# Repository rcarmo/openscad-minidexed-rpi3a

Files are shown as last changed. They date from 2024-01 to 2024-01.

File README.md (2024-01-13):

# MiniDexed RPI 3A Case

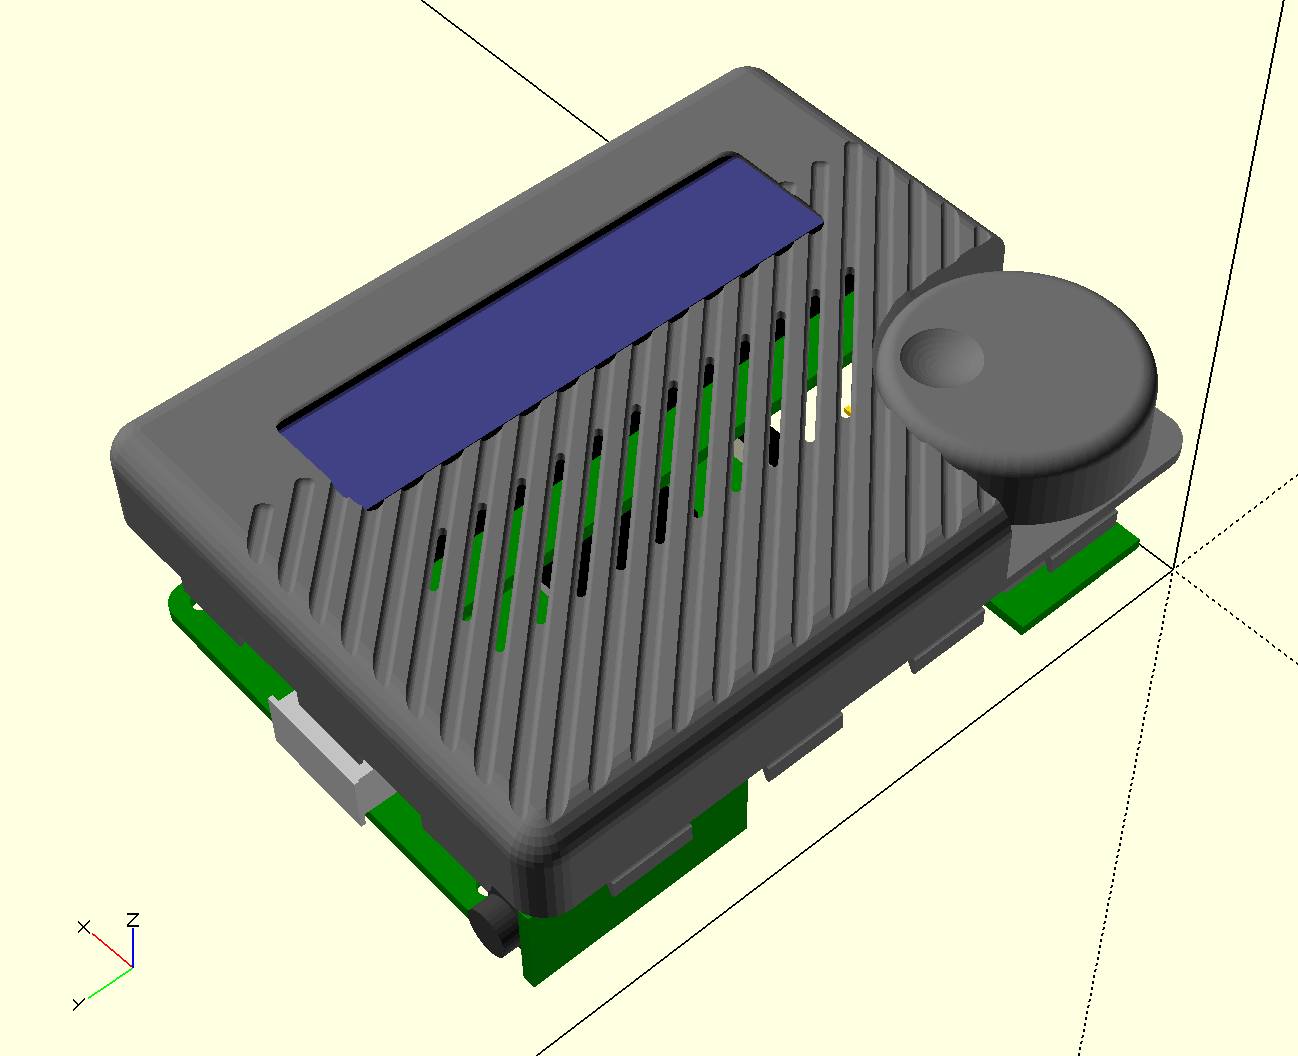
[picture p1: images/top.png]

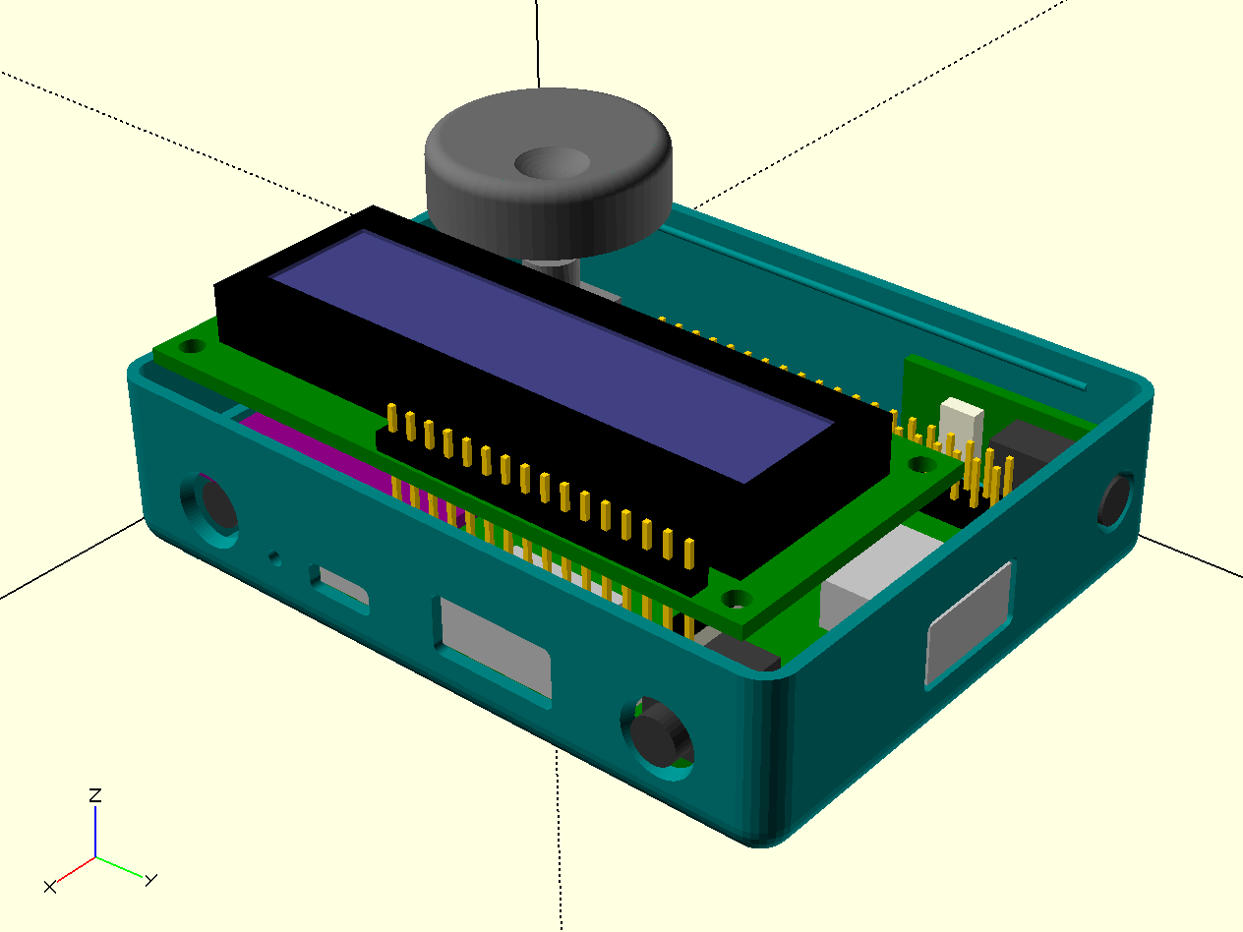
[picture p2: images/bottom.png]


This is a case for a [MiniDexed] synthesizer built with a Raspberry Pi 3A, a DAC and a custom board for a MIDI IN TRS jack (schematic included in the `kicad-mini-in` folder--I ended up just using a protoboard, so there's no real PCB data for that).

This repository includes the `STL` files for the case (top, bottom and knob), as well as the [OpenSCAD](https://openscad.org) files for the case and all boards (some of which I modified from some of the excellent libraries I keep tabs on [here](https://taoofmac.com/space/apps/openscad)).

There is also an (incomplete) slanted/oblique version of the case, which I may or may not finish.

## MIDI IN Schematic

This is a pretty simple schematic, and I ended up just using a protoboard for it. The TRS jack is a 2.5mm MIDI IN jack, and other than the [`H11L1M`](https://www.onsemi.com/products/interfaces/high-performance-optocouplers/high-speed-logic-gate-optocouplers/h11l1m) optocoupler, everything else is just a few resistors and capacitors:

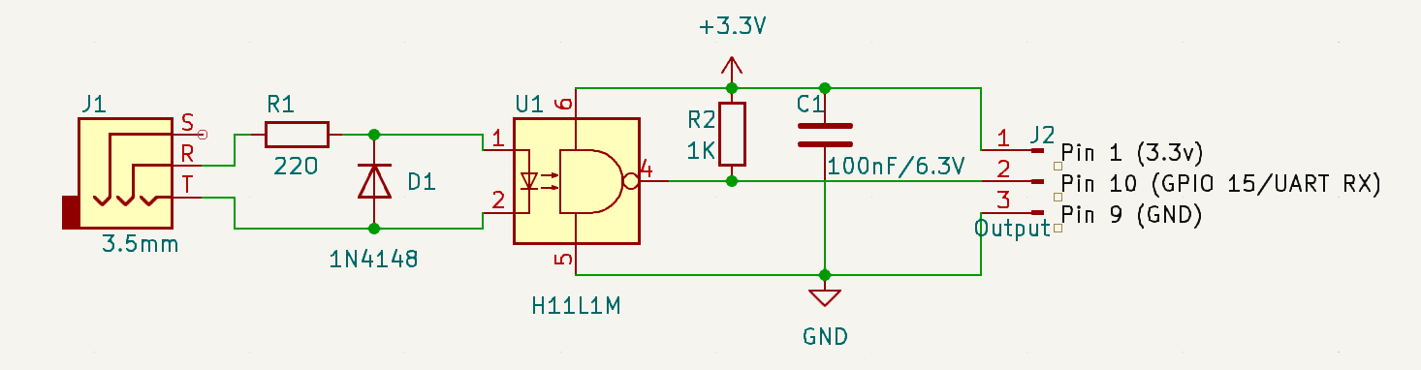
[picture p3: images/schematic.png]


## Checklist

- [x] Check all screw hole sizes
- [x] Knob
- [x] Deeper top pattern (0.5mm)
- [x] LED hole
- [x] Wider SD card slot inset
- [x] MIDI TRS jack

## Printing Notes

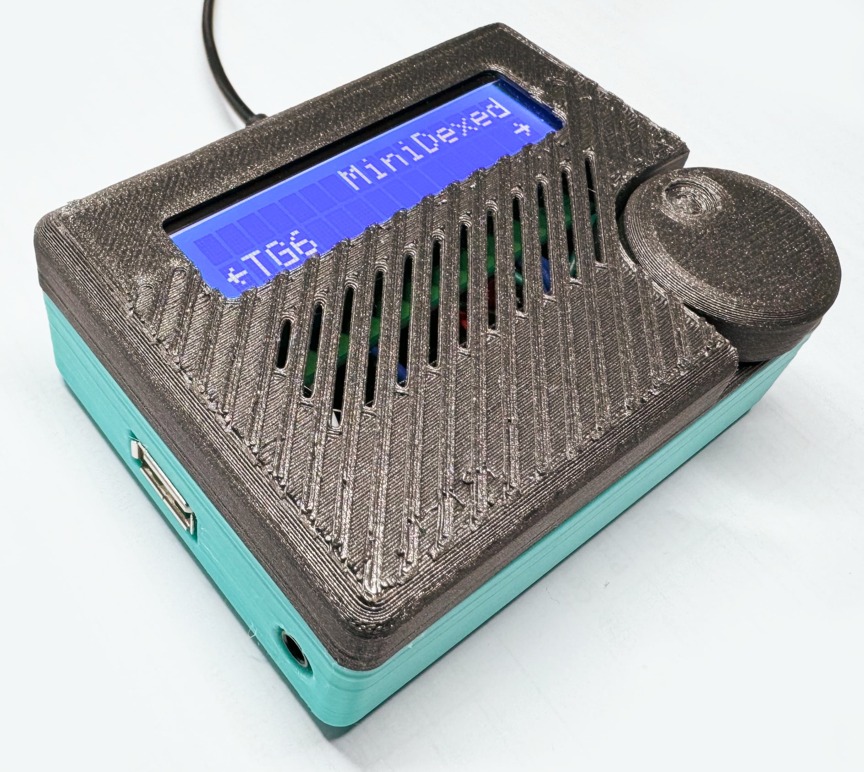
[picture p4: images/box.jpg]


Printed in PLA, 0.2mm layer height, 3 perimeters, 3 top/bottom layers. I used Sunlu PLA+ for the bottom half of the case and Eryone Galaxy Black for the top and knob.

You may want to print the top half of the case with a plain face, but I went for a little more texture (which may or may not work well depending on PLA and lighting). I recommend printing the flat face down, and using mouse ear brims to keep it from warping (although the supports will help with that, too).

[MiniDexed]: https://github.com/probonopd/MiniDexed

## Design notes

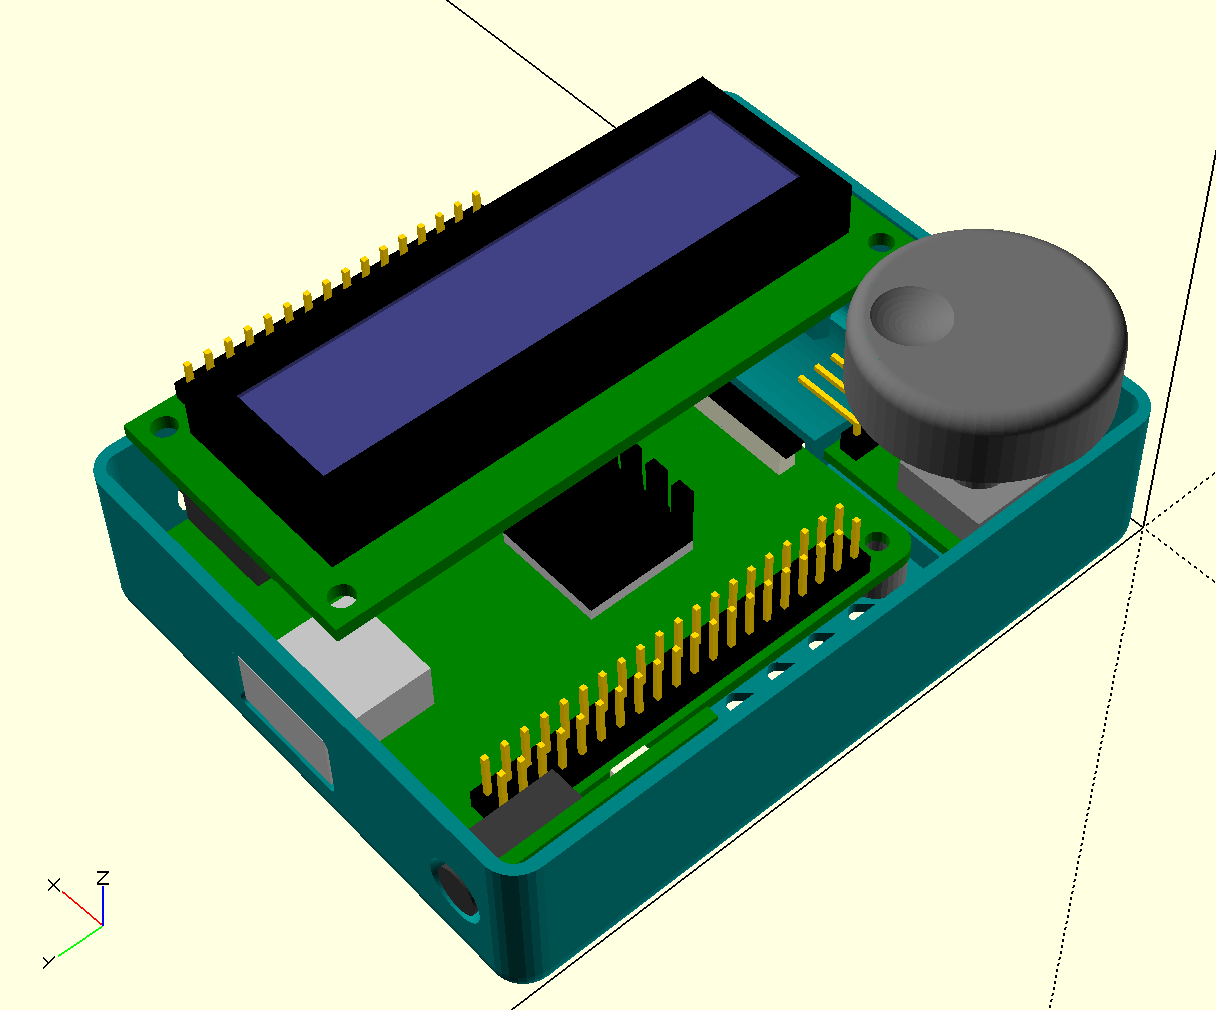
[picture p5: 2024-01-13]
images/top_board.png

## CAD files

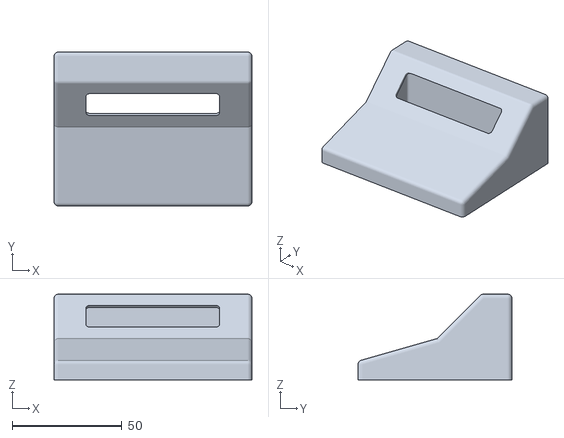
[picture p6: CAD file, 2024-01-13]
oblique/oblique_top.stl
90.0 x 70.0 x 39.0

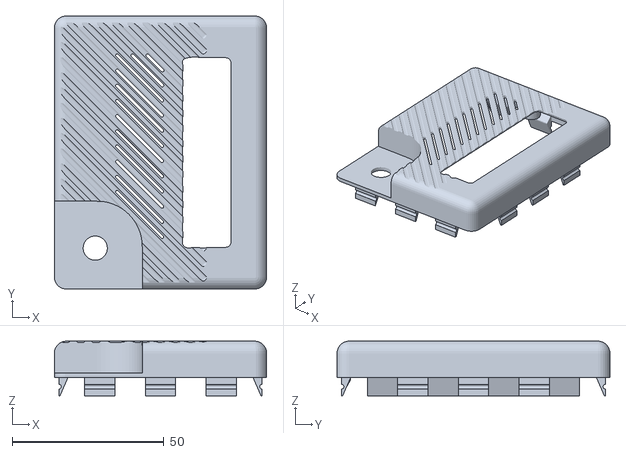
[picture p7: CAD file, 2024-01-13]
STLs/minidexed_top.stl
70.0 x 90.0 x 18.0

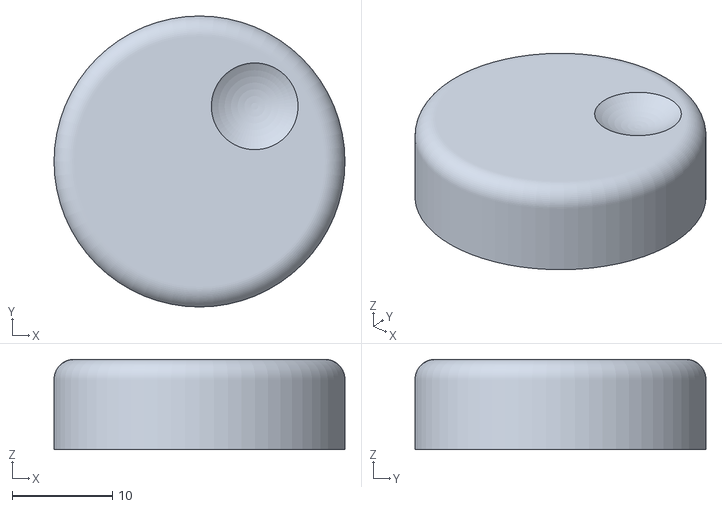
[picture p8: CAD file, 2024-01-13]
STLs/minidexed_knob.stl
29.0 x 29.0 x 9.00

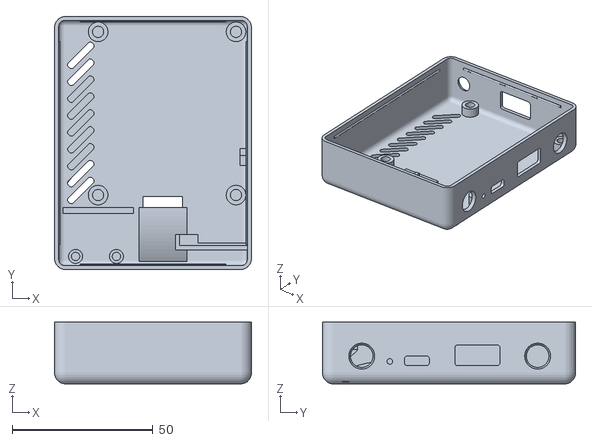
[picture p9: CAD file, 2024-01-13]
STLs/minidexed_bottom.stl
70.0 x 90.0 x 22.0

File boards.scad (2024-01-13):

include <connectors.scad>

interf = 0.1;
$incolor = (is_undef($incolor)) ? true : $incolor;
$alpha = (is_undef($alpha)) ? 1 : $alpha;

//------------------------------------------------------------------------
// m25_standard_hole Standard fit M2.5 hole size definition
//------------------------------------------------------------------------
module m25_standard_hole() {
	circle(r=(2.75 / 2), $fn=16);
}

//------------------------------------------------------------------------
// Move copies of children to positions in passed array
//------------------------------------------------------------------------
module array_holes(pos) {
	for (pos=pos) {			
		translate(pos) children();
	}
}

//------------------------------------------------------------------------
// Raspberry Pi Model A+ rev.1.1
//------------------------------------------------------------------------
module pi_3a(heatsink=true) {

    $fn = 32;
    x  = 56;     y = 65;    z = 1.60;  // Measured PCB size
    hx = 11.40; hy = 15.1; hz = 6.15;  // Measured HDMI connector size
    ux = 13.25; uy = 13.8; uz = 6.0;   // Measured USB connector size
    mx =  5.60; my =  7.6; mz = 2.40;  // Measured micro USB power connector size
    boardc = $incolor ? "green" : undef;
    heatc  = $incolor ? "black" : undef;
    cpuc   = $incolor ? "lightgrey" : undef;

    // The origin is the lower face of PCB.
    translate([0, 0, z]) {
        translate([1.0, 7.1, 0])                    pin_headers(2, 20);
        translate([x - hx + 1, 32.0 - (hy / 2), 0]) hdmi_connector(hx, hy, hz);
        translate([x - mx + 1, 10.6 - (my / 2), 0]) microusb_connector(mx, my, mz);
        translate([18, y - 12, 0.8])                usb_connector(ux, uy, uz);
        translate([20.5, 1.4, -z*2])                micro_sd_card();
        translate([17.5, 2.5, 0])                   spi_connector();
        translate([35.5, 44, 0])                    spi_connector();
        
        translate([x - 12.8, 50, 0])                audio_video(12.8);
        translate([x + 2.2, 10.55, 1.2])            rotate(a=270, v=[0, 0, 1]);
        translate([16, 19, 0]) {
            color(cpuc) cube([14.5, 14.5, 1.5]);
            if(heatsink)
                translate([0,0,1.5]) color(heatc) {
                    cube([14.5, 14.5, 1.5]);
                    translate([0,0,1.5]) 
                    for(x=[0: 4.1: 14.5], y=[0: 3.3: 14]) {
                        translate([x,y,0]) cube([2.2, 1.2, 6.5]);
                    }
                }
        }
        translate([0, 0, -z]) {
            color(boardc) linear_extrude(height=z)
                difference() {
                    hull() {
                        translate([  3,   3]) circle(r=3);
                        translate([x-3,   3]) circle(r=3);
                        translate([x-3, y-3]) circle(r=3);
                        translate([  3, y-3]) circle(r=3);
                    }
                    pi_3a_holes();
                }
        }
    }
}

module pi_3a_holes() {
 	off=3.5;
	x=49 + off;
	y=58 + off;
	holes=[
		[off,off], [x, off],
		[off, y],  [x, y]
	];
	
	if ($children > 0) {
		array_holes(pos=holes) children();
	} else {
		array_holes(pos=holes) m25_standard_hole();		
	}
}

module pi_3a_mounts(height=2, hole=2, thickness=2) {
    $fn = 32;
	mountc  = $incolor ? "grey"  : undef;
    pi_3a_holes() {
        color(mountc) linear_extrude(height) difference() {
            circle(r=hole/2 + thickness);
            circle(r=hole/2);
        }
    }
}


//------------------------------------------------------------------------
// 1602A LCD panel 16x2 characters.
//------------------------------------------------------------------------
module lcd_1602a() {
    $fn = 32;
	boardc  = $incolor ? "green"  : undef;
	metalc  = $incolor ? "black"  : undef;
	lcdc  = $incolor ? [64/255, 64/255, 128/255] : undef;

    translate([4.5, 5.5, 1.8])  
        difference() {
            color(metalc) cube([71, 24, 7]);
            translate([3.2, 4.8, 6.5])
                color(lcdc) cube([64.4, 14.4, 8]);
        }
    color(boardc) linear_extrude(height = 1.8) difference() {
        square(size=[80, 36]);
        lcd_1602a_holes() {
            circle(r=3/2);
        }
    }
    translate([33, 3, 4]) 
        rotate([180,0,0]) pin_headers(16,1);
}

module lcd_1602a_holes() {
    holes = [
        [3, 3], [80 - 3, 3],
        [80 - 3, 36 - 3], [3, 36 - 3]
    ];
	
	if ($children > 0) {
		array_holes(pos=holes) children();
	} else {
		array_holes(pos=holes) m25_standard_hole();		
	}
}

module lcd_1602a_mounts(height=2, hole=2.5, thickness=2) {
    $fn = 32;
	mountc  = $incolor ? "grey"  : undef;
    lcd_1602a_holes() {
        color(mountc) linear_extrude(height=height) difference() {
            circle(r=hole/2 + thickness);
            circle(r=hole/2);
        }
    }
}



//------------------------------------------------------------------------
// HW-040 Rotary Encoder
//------------------------------------------------------------------------

module encoder_hw_040() {
    $fn = 32;
	boardc  = $incolor ? "green"  : undef;
	metalc  = $incolor ? "grey"  : undef;
    color(boardc) linear_extrude(height = 1.4) difference() {
        square(size=[26, 18.5]);
        encoder_hw_040_holes() {
            circle(r=2.5/2);
        }
    }
    color(metalc) union() {
        translate([4.5, 4.5, 1.4]) cube([12, 12, 4.5]);
        translate([10.5, 10.5, 8.9]) cylinder(7, 3.5, 3.5, true);
        translate([10.5, 10.5, 12]) cylinder(7, 2, 2, true);
        translate([10.5, 10.5, 13]) difference() {
            cylinder(14, 3, 3);
            translate([-3, 1.5, 3.5]) cube([6, 5, 12]);
        }
    }
    translate([22.5, 17, 3.4]) rotate([0, 0, -90]) pin_right_angle_low(5);
}

module encoder_hw_040_holes() {
    holes = [
        [4.5, 1.7], [19.0, 1.7]
    ];
	
	if ($children > 0) {
		array_holes(pos=holes) children();
	} else {
		array_holes(pos=holes) m25_standard_hole();		
	}
}

module encoder_hw_040_mounts(height=2, hole=2, thickness=2) {
    $fn = 32;
	mountc  = $incolor ? "grey"  : undef;
    encoder_hw_040_holes() {
        color(mountc) linear_extrude(height) difference() {
            circle(r=hole/2 + thickness);
            circle(r=hole/2);
        }
    }
}



//------------------------------------------------------------------------
// HW-575 Dual Linear Pot
//------------------------------------------------------------------------

module fader_hw_575() {
    $fn = 32;
	boardc  = $incolor ? "lightblue"  : undef;
	metalc  = $incolor ? "silver"  : undef;
	feltc   = $incolor ? "black"  : undef;
    color(boardc) linear_extrude(height = 1.4) difference() {
        square(size=[38.8, 117.3]);
        fader_hw_575_holes() {
            circle(r=3.7/2);
        }
    }
    color(metalc) union() {
        translate([3, 20, 1.4]) 
            cube([12.3, 88, 12.3]);
        translate([23.5, 20, 1.4]) 
            cube([12.3, 88, 12.3]);
        translate([8.5, 25, 13.7]) 
            cube([1.4, 6, 10]);
        translate([29, 95, 13.7]) 
            cube([1.4, 6, 10]);
    }
    color(feltc) union() {
        translate([3.2, 20, 13.6]) 
            cube([11.8, 88, 0.2]);
        translate([23.7, 20, 13.6]) 
            cube([11.8, 88, 0.2]);        
    }
    translate([28.3, 14.5, 3.4]) 
       rotate([0,0,180]) {
          pin_right_angle_low(3);
          translate([10,0,0])
              pin_right_angle_low(3);
       }    
}


module fader_hw_575_holes() {
    w = 38.8;
    l = 117.3;
    x = 3.2;
    y = 3.7;
    holes = [
        [x, y], [w-x, y],
        [x, l-y], [w-x, l-y],
    ];
	
	if ($children > 0) {
		array_holes(pos=holes) children();
	} else {
		array_holes(pos=holes) m25_standard_hole();		
	}
}


module fader_hw_575_mounts(height=2, hole=2, thickness=2) {
    $fn = 32;
	mountc  = $incolor ? "grey"  : undef;
    fader_hw_575_holes() {
        color(mountc) linear_extrude(height) difference() {
            circle(r=hole/2 + thickness);
            circle(r=hole/2);
        }
    }
}

//------------------------------------------------------------------------
// CJMCU-5102 DAC
//------------------------------------------------------------------------


module cjmcu_5102() {
    $fn = 32;
	boardc  = $incolor ? "purple"  : undef;
	chipc   = $incolor ? "black"  : undef;
    color(boardc) linear_extrude(height = 1.6) 
        square(size=[23.6, 31.6]);
    translate([14.7,9,1.6])
        rotate([0,0,180])
            audio_video(12);
    color(chipc)
        translate([4.5, 23.2, 1.6]) 
            cube([6.5, 4.3, 1]);
    //translate([21, 28.4, 3.4]) 
    //   rotate([0,0,-90])
    //      pin_right_angle_low(10);
}

//------------------------------------------------------------------------
// Custom protoboard for MIDI In
//------------------------------------------------------------------------
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

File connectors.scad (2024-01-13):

$incolor = (is_undef($incolor)) ? true : $incolor;


module pin_headers(cols, rows) {
    w = 2.54; h = 2.54; p = 0.65;
	pinc  = $incolor ? "gold"  : undef;
	basec = $incolor ? "black" : undef;
	
    for(x = [0 : (cols -1)]) {
        for(y = [0 : (rows  - 1)]) {
            translate([w * x, w * y, 0]) {
                union() {
                    color(basec) cube([w, w, h]);
                    color(pinc)  translate([(w - p) / 2, (w - p) / 2, -3]) cube([p, p, 11.54]);
                }
            }
        }
    }
}

module pin_right_angle_low(cols) {
    w = 2.54; p = 0.65;
	pinc  = $incolor ? "gold"  : undef;
	basec = $incolor ? "black" : undef;
    d = (w - p) / 2;
    for(x = [0 : (cols -1)]) {
        translate([w * x, 0, 0]) {
            color(basec) translate([0, d - 1, -2]) cube([w, w, w]);
            color(pinc)  translate([d, d, -4]) cube([p, p, 5 + w / 2]);
            color(pinc)  translate([d, d + 7 + w, d + 1]) rotate(a=90, v=[1, 0, 0]) cube([p, p, 5 + w + 2]);
        }
    }
}

module usb_connector(x, y, z) {
    f = 0.6; // Flange
	shieldc = $incolor ? "silver" : undef;
    color(shieldc) { 
		cube([x, y, z]);
		translate([-f, y - f, -f])
			cube([x + f * 2, f, z + f * 2]);
	}
}

module audio_jack() {
    x = 11.4; y = 12; z = 10.2;
    d = 6.7; h = 3.4;
    color("blue") cube([x, y, z]);
    translate([-h, y / 2, (d / 2) + 3])
        rotate(a=90, v=[0, 1, 0])
            color("blue") cylinder(r=(d / 2), h=h);
}

module hdmi_connector(x, y, z) {
	shieldc = $incolor ? "silver" : undef;
    color(shieldc) cube([x, y, z]);
}

module microusb_connector(x, y, z) {
	shieldc = $incolor ? "silver" : undef;
    color(shieldc) cube([x, y, z]);
}

module spi_connector() {
	basec = $incolor ? "beige" : undef;
	snapc = $incolor ? "black" : undef;
    color(basec) cube([20, 2.4, 3.5]);
    translate([-1, 0, 3.5])
        color(snapc) cube([22, 2.4, 1.4]);
}

module micro_sd_card() {
	shieldc = $incolor ? "silver" : undef;
	cardc = $incolor ? "black" : undef;
    color(shieldc) cube([12, 11.3, 1.5]);
    translate([0.5, -4,0.25])
    color(cardc) cube([11,4,1]);    
}

module audio_video(size_x) {
	avc = $incolor ? [58/255, 58/255, 58/255] : undef;
    color(avc) {
        cube([size_x, 7, 5.6]);
        translate([size_x, 7 / 2, 5.6 / 2]) rotate([0,90,0]) cylinder(d=5.6, h=2.6);
    }
}

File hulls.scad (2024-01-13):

$incolor = 1;
$knob = 0;
$cases = 1;
$boards = 0;
$alpha = 0.5;
$mounts = 0;
depth = 70;
width = 90;
height = 50;
bottom_height = 15;
thickness = 1.5;
radius = 2;
bottom_height = 15;
lod = 64;
$fs = 0.01;


module case_envelope(depth, width, radius) {
    roundedcube([depth, width, 90], false, radius=radius, "z");
}

module case_bottom() {
    intersection() {
        difference() {
            case_envelope(depth, width, radius);
            translate([thickness, thickness, thickness])
                case_envelope(depth-thickness*2, width-thickness*2, radius/thickness);
        }
        cube([depth, width, bottom_height]);
    }
}

module top_lcd_cutout() {
    translate([14.4,10.5,-thickness/2])
        roundedcube([61, 14.4, thickness*2], radius=2);
}

 module top_button_panel() {
     cube([depth+20, width, thickness]);
 }
 
 module fillet(r) {
   offset(r = -r) {
     offset(delta = r) {
       children();
     }
   }
}


module case_assembly() {
    // top section
    intersection() {
        case_envelope(depth, width, radius);
        union() {
            translate([0,0,57])
                rotate([0,45,0])
                    top_lcd_panel();
            translate([0,0,34])
                rotate([0,15,0])
                    top_button_panel();
        }
    }   
    case_bottom();
}


module base_outline() {
        union() {
            fillet(-radius)
              fillet(radius)
                polygon([[0,0], [0,20], [40,30], [60,50], [70,50], [70,0], [0,0]]);
            square([depth, 10]);
        }
}

module side_section() {
    rotate([90,0,0])
    linear_extrude(width)
        difference() {
            base_outline();
            offset(-thickness) base_outline();
        }
}


module outer_case_hull(width, depth, segments, thickness, radius) {
    union() 
        for(s = segments)
            hull()
                for(
    
    {
        hull()
            for(x = [0: width-radius*2: width])
                translate([x+radius, 0, 0])
                    for(pos = [[0,0], [0,20], [35,30], [35,0]])
                        translate([0, pos[0]+radius, pos[1]+radius])
                            sphere(radius);                    
        hull()
            for(x = [0: width-radius*2: width])
                translate([x+radius, 0, 0])
                    for(pos = [[35,30], [55,50], [depth-radius*2,50], [depth-radius*2,0], [35,0]])
                        translate([0, pos[0]+radius, pos[1]+radius])
                            sphere(radius);
        roundedcube([width, depth, 10], false, radius=radius, "z");
    }
}

outer_case_hull(width, depth, [
    [[0,0], [0,20], [35,30], [35,0], [35,30], [55,50]], 
    [[depth-radius*2,50], [depth-radius*2,0], [35,0]]], thickness, radius);

module inner_case_hull() {
    union() {
        hull()
            for(x = [thickness: width-radius-thickness*2: width])
                translate([x+radius/2, 0, 0])
                    for(pos = [[0,0], [0,20-thickness/2], [35,30-thickness/2], [35,0]])
                        translate([0, pos[0]+radius/2+thickness, pos[1]+radius/2+thickness])
                            sphere(radius/2);                    
        hull()
            for(x = [thickness: width-radius-thickness*2: width])
                translate([x+radius/2, 0, 0])
                    for(pos = [[35,30-thickness/2], [55,50-thickness/2], [depth-radius*2-thickness/2,50-thickness/2], [depth-radius*2-thickness/2,0], [35,0]])
                        translate([0, pos[0]+radius/2+thickness, pos[1]+radius/2+thickness])
                            sphere(radius/2);
    }
}

module case_hull() {
    difference() {
        difference() {
            outer_case_hull();
            inner_case_hull();
        }
    }
}

module case_bottom() {
    intersection() {
        case_hull();
        cube([width, depth, bottom_height]);
    }
}

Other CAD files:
STLs/minidexed_top_plain.stl
minidexed.scad
oblique/oblique_box.scad
roundedcube.scad

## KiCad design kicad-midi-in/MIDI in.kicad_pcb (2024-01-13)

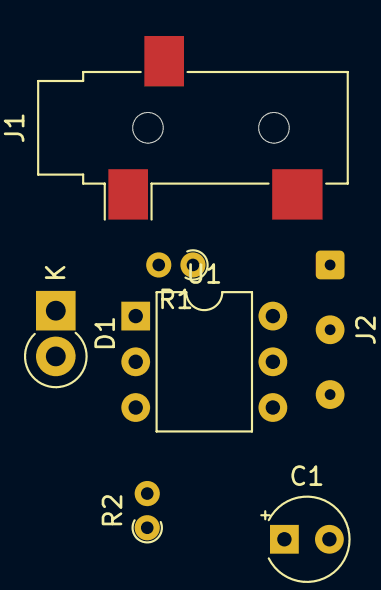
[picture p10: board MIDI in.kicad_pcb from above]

Board: 2 copper layers, 7 parts (0 on the bottom side), 6 nets, no tracks yet.

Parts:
C1: 100nF/6.3V; CP_Radial_Tantal_D4.5mm_P2.50mm
D1: 1N4148; D_DO-41_SOD81_P2.54mm_Vertical_KathodeUp
J1: 3.5mm; Jack_3.5mm_CUI_SJ-3523-SMT_Horizontal
J2: Output; SolderWire-0.1sqmm_1x03_P3.6mm_D0.4mm_OD1mm
R1: 22O; R_Axial_DIN0204_L3.6mm_D1.6mm_P1.90mm_Vertical
R2: 1K; R_Axial_DIN0204_L3.6mm_D1.6mm_P1.90mm_Vertical
U1: H11L1M; DIP-6_W7.62mm

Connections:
+3V3: C1.1, J2.PI PIN 1 (Pin_1), R2.1, U1.6
GND: C1.2, J2.PI PIN 9 (Pin_3), U1.5
unnamed: D1.1 (K), R1.2, U1.1
unnamed: D1.2 (A), J1.T, U1.2
unnamed: J1.R, R1.1
unnamed: J2.PI PIN 10 (Pin_2), R2.2, U1.4
